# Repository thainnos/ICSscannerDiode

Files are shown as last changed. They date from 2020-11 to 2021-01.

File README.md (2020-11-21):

# A Secure Network Scanner Architecture for Asset Management in Strongly Segmented ICS Networks






<table align="center"><tr><td align="center" width="9999">

</td></tr></table>

This GIT provides all necessary material to setup the network scanner for industrial networks.
The network scanner is based on a strict segmentation between the OT and IT network.
For this two Raspberry Pis, one in the IT network and the other in the OT network are used.
These are communicating over a SPI bus with each other, where a microcontroller is placed in acting
as a data filter/diode.

## Prototype
All this is implemented on a central PCB, where all parts get attached to.
The image below shows the PCB of the network scanner.

<table align="center"><tr><td align="center" width="9999">
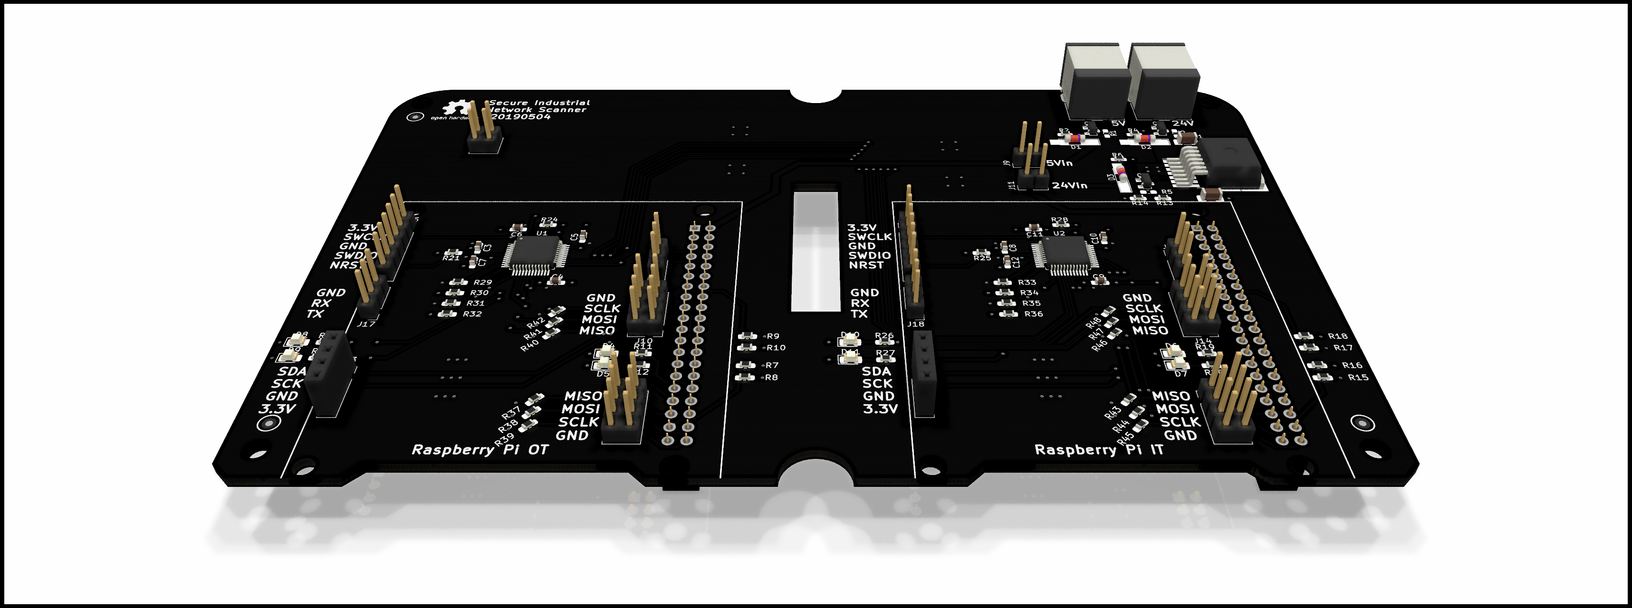
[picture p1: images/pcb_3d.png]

</td></tr></table>

A fully assebled network scanner, with the two Raspberry Pis and OLED displays is illustraed below.

<table align="center"><tr><td align="center" width="9999">

</td></tr></table>

## Scan control and results (Web frontend)

The scan can be started and stopped over the web frontend.
<table align="center"><tr><td align="center" width="9999">
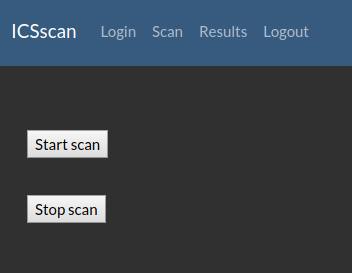
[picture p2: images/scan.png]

</td></tr></table>

The results are shown in a table.
<table align="center"><tr><td align="center" width="9999">
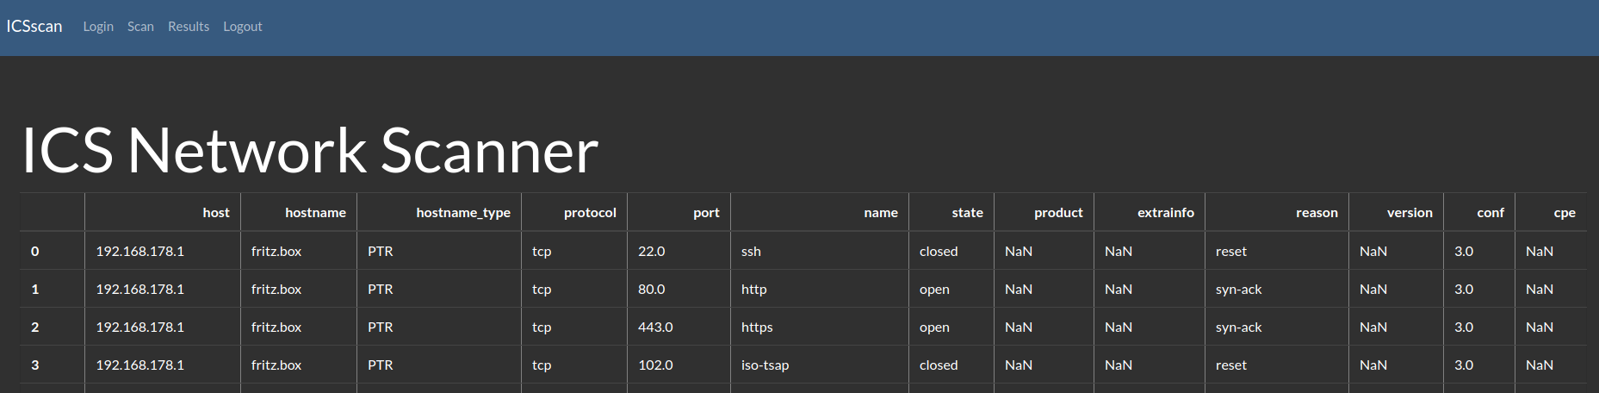
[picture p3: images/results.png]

</td></tr></table>

## Content
* [Software](software/README.md)
* [Hardware](hardware/README.md)
* [Images](images/README.md)

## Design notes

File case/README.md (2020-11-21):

# Case/Mounting Plate for Network Scanner

Modelling with OpenSCAD
'''zsh
sudo add-apt-repository ppa:openscad/releases
sudo apt-get install openscad
'''

Printing with CURA

## 3D Printing

Start the printing and grab a coffee.

<table align="center"><tr><td align="center" width="9999">
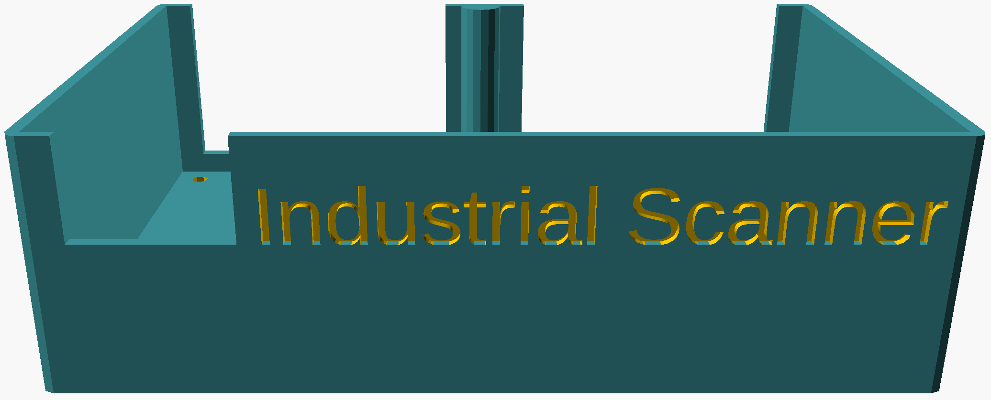
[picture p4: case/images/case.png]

</td></tr></table>

<table align="center"><tr><td align="center" width="9999">
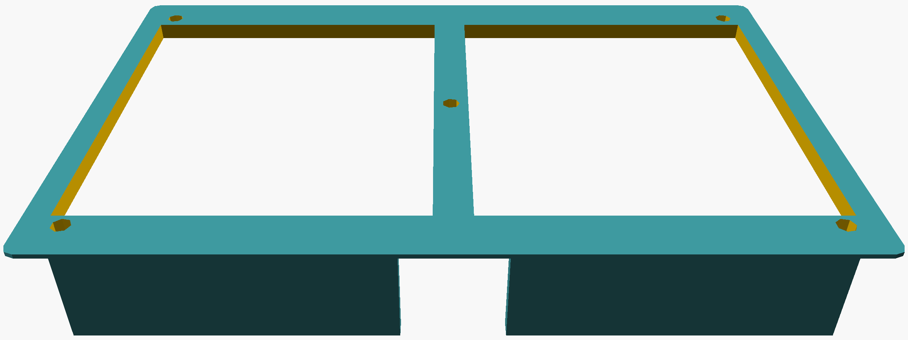
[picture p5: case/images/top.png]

</td></tr></table>

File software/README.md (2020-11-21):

# Software for the Network Scanner

## Components
- [Scanner](scanner/README.md)
- [STM32F030CC](stm32f030cc/README.md)

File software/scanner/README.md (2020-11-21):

# Software Running on each Raspberry Pi for Scanning and Communication Tasks

## Enable I2C, SPI and SSH
```sh
sudo raspi-config
```

## Install dependencies 
Install requirements of python scanner

```sh
python3 -m pip install -r requirements.txt
```

```sh
sudo apt install nmap
```

## Enable booth SPI in bootconfig

```sh
dtparam=spi=on
dtoverlay=spi1-3cs
```

## Enabling autostart

```sh
sudo vim /etc/rc.local
```

```sh
cd /home/pi/gits/networkScanner/software/scanner/
python3 scanner.py
```

## Generating certificates for the Office HTTPs webside

```sh
mkdir certs
cd certs
openssl req -x509 -newkey rsa:4096 -nodes -out cert.pem -keyout key.pem -days 365
```

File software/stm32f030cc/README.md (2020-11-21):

# Software for the STM32 Microcontrollers 

## Toolchain
One possibility is to use the official toolchain provided by ARM ([ARM Toolchain](https://developer.arm.com/tools-and-software/open-source-software/developer-tools/gnu-toolchain/gnu-rm)).
Another possibility is to use the toolchain included by the distribution.

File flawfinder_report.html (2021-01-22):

# Flawfinder Results

Here are the security scan results from Flawfinder version 2.0.15 (https://dwheeler.com/flawfinder), (C) 2001-2019 David A. Wheeler (https://dwheeler.com). Number of rules (primarily dangerous function names) in C/C++ ruleset: 222

Examining ./software/stm32f030cc/Middlewares/Third_Party/FreeRTOS/Source/portable/MemMang/heap_5.c
Examining ./software/stm32f030cc/Middlewares/Third_Party/FreeRTOS/Source/portable/MemMang/heap_4.c
Examining ./software/stm32f030cc/Middlewares/Third_Party/FreeRTOS/Source/portable/MemMang/heap_2.c
Examining ./software/stm32f030cc/Middlewares/Third_Party/FreeRTOS/Source/portable/MemMang/heap_3.c
Examining ./software/stm32f030cc/Middlewares/Third_Party/FreeRTOS/Source/portable/MemMang/heap_1.c
Examining ./software/stm32f030cc/Middlewares/Third_Party/FreeRTOS/Source/portable/GCC/ARM_CM0/port.c
Examining ./software/stm32f030cc/Middlewares/Third_Party/FreeRTOS/Source/portable/GCC/ARM_CM0/portmacro.h
Examining ./software/stm32f030cc/Middlewares/Third_Party/FreeRTOS/Source/stream_buffer.c
Examining ./software/stm32f030cc/Middlewares/Third_Party/FreeRTOS/Source/timers.c
Examining ./software/stm32f030cc/Middlewares/Third_Party/FreeRTOS/Source/tasks.c
Examining ./software/stm32f030cc/Middlewares/Third_Party/FreeRTOS/Source/queue.c
Examining ./software/stm32f030cc/Middlewares/Third_Party/FreeRTOS/Source/include/mpu_wrappers.h
Examining ./software/stm32f030cc/Middlewares/Third_Party/FreeRTOS/Source/include/stack_macros.h
Examining ./software/stm32f030cc/Middlewares/Third_Party/FreeRTOS/Source/include/croutine.h
Examining ./software/stm32f030cc/Middlewares/Third_Party/FreeRTOS/Source/include/queue.h
Examining ./software/stm32f030cc/Middlewares/Third_Party/FreeRTOS/Source/include/deprecated_definitions.h
Examining ./software/stm32f030cc/Middlewares/Third_Party/FreeRTOS/Source/include/task.h
Examining ./software/stm32f030cc/Middlewares/Third_Party/FreeRTOS/Source/include/portable.h
Examining ./software/stm32f030cc/Middlewares/Third_Party/FreeRTOS/Source/include/timers.h
Examining ./software/stm32f030cc/Middlewares/Third_Party/FreeRTOS/Source/include/semphr.h
Examining ./software/stm32f030cc/Middlewares/Third_Party/FreeRTOS/Source/include/StackMacros.h
Examining ./software/stm32f030cc/Middlewares/Third_Party/FreeRTOS/Source/include/FreeRTOSConfig_template.h
Examining ./software/stm32f030cc/Middlewares/Third_Party/FreeRTOS/Source/include/mpu_prototypes.h
Examining ./software/stm32f030cc/Middlewares/Third_Party/FreeRTOS/Source/include/message_buffer.h
Examining ./software/stm32f030cc/Middlewares/Third_Party/FreeRTOS/Source/include/list.h
Examining ./software/stm32f030cc/Middlewares/Third_Party/FreeRTOS/Source/include/projdefs.h
Examining ./software/stm32f030cc/Middlewares/Third_Party/FreeRTOS/Source/include/stream_buffer.h
Examining ./software/stm32f030cc/Middlewares/Third_Party/FreeRTOS/Source/include/event_groups.h
Examining ./software/stm32f030cc/Middlewares/Third_Party/FreeRTOS/Source/include/FreeRTOS.h
Examining ./software/stm32f030cc/Middlewares/Third_Party/FreeRTOS/Source/event_groups.c
Examining ./software/stm32f030cc/Middlewares/Third_Party/FreeRTOS/Source/croutine.c
Examining ./software/stm32f030cc/Middlewares/Third_Party/FreeRTOS/Source/list.c
Examining ./software/stm32f030cc/Middlewares/Third_Party/FreeRTOS/Source/CMSIS_RTOS/cmsis_os.c
Error: encoding error in ./software/stm32f030cc/Middlewares/Third_Party/FreeRTOS/Source/CMSIS_RTOS/cmsis_os.c 'utf-8' codec can't decode byte 0xa9 in position 1078: invalid start byte Python3 requires input character data to be perfectly encoded; it also requires perfectly correct system encoding settings. Unfortunately, your data and/or system settings are not. Here are some options: 1. Run: PYTHONUTF8=0 python3 flawfinder if your system and and data are all properly set up for a non-UTF-8 encoding. 2. Run: PYTHONUTF8=0 LC_ALL=C.ISO-2022 python3 flawfinder if your data has a specific encoding such as ISO-2022 (replace "ISO-2022" with the name of your encoding, and optionally replace "C" with your native language). 3. Run: PYTHONUTF8=0 LC_ALL=C.ISO-8859-1 python3 flawfinder if your data has an unknown or inconsistent encoding (ISO-8859-1 encoders normally allow anything). 4. Convert all your source code to the UTF-8 encoding. The system program "iconv" or Python program "cvt2utf" can do this (for cvt2tuf, you can use "pip install cvt2utf"). 5. Run: python2 flawfinder (That is, use Python 2 instead of Python 3). Some of these options may not work depending on circumstance. In the long term, we recommend using UTF-8 for source code. For more information, see the documentation.

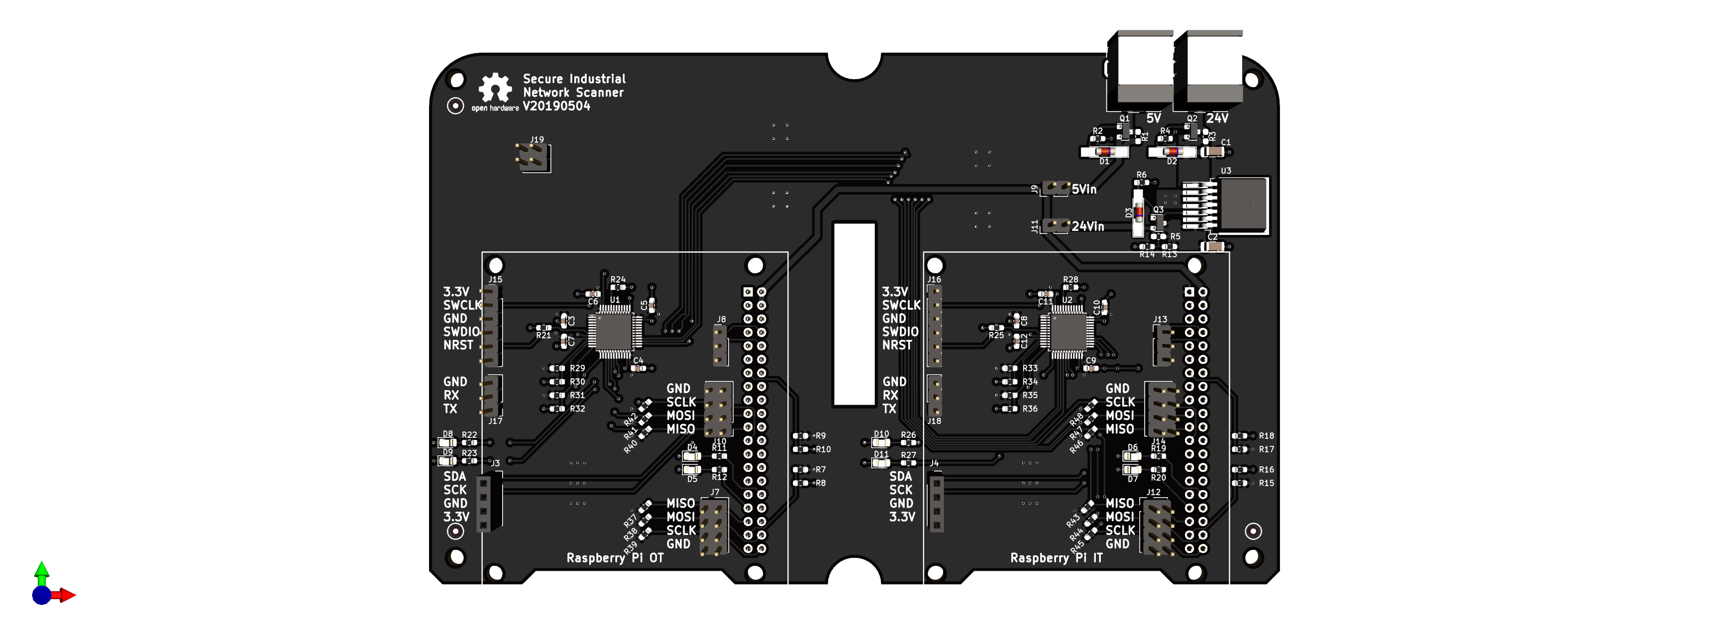
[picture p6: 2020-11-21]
images/pcb_top.png

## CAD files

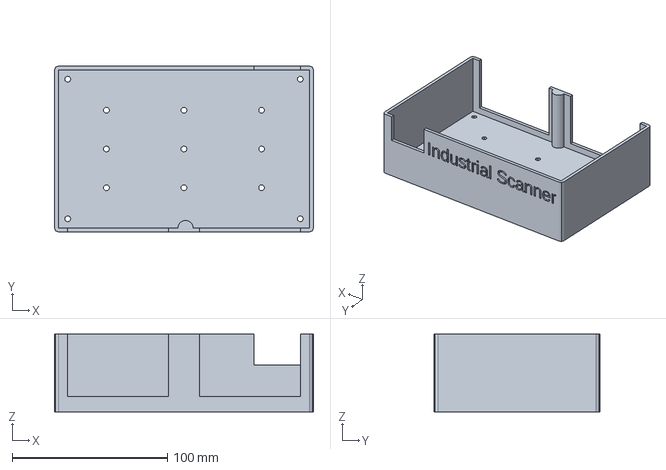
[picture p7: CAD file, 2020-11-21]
case/production_data/Case/case.3mf
167.0 x 107.0 x 50.0 mm

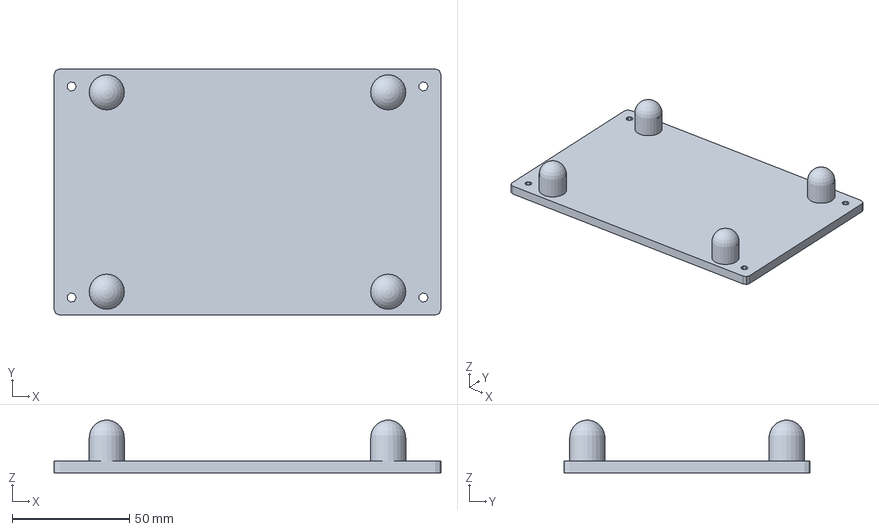
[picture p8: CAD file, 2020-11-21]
case/production_data/Plate/mounting_plate.3mf
165.0 x 105.0 x 22.4 mm

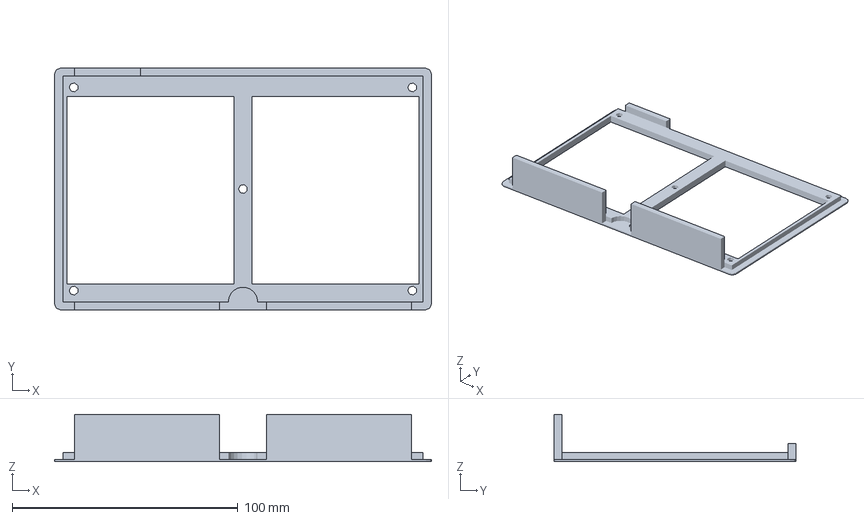
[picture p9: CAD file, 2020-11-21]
case/production_data/top/top.3mf
167.0 x 107.0 x 21.0 mm

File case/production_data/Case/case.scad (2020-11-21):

content = "Industrial Scanner";
font = "Liberation Sans";

union() difference() { 
    translate([-1,-1,0])
    cube(size = [162,102,5], center = false);
    // PCB mount
    translate([5,5,0])
    cylinder( d = 4.00, h = 20);
    translate([155,5,0])
    cylinder( d = 4.00, h = 20);
    translate([5,95,0])
    cylinder( d = 4.00, h = 20);
    translate([155,95,0])
    cylinder( d = 4.00, h = 20);
    
    // Case mount
    translate([30,25,0])
        cylinder( d = 4.00, h = 20);
    translate([80,25,0])
        cylinder( d = 4.00, h = 20);
    translate([130,25,0])
        cylinder( d = 4.00, h = 20);
    translate([30,50,0])
        cylinder( d = 4.00, h = 20);
    translate([80,50,0])
        cylinder( d = 4.00, h = 20);
    translate([130,50,0])
        cylinder( d = 4.00, h = 20);
    translate([30,75,0])
        cylinder( d = 4.00, h = 20);
    translate([80,75,0])
        cylinder( d = 4.00, h = 20);
    translate([130,75,0])
        cylinder( d = 4.00, h = 20);
       
} 



// Rounded corners
union() difference() { // front left
    translate([-1,-1,0])
        cylinder( d = 5.00, h = 50);
    translate([-1,-1,0])
        cube(size = [5,5,50], center = false);
} 
union() difference() { // front right
    translate([161,-1,0])
        cylinder( d = 5.00, h = 50);
    translate([156,-1,0])
        cube(size = [5,5,50], center = false);
} 
union() difference() { // back right
    translate([161,101,0])
        cylinder( d = 5.00, h = 50);
    translate([156,96,0])
        cube(size = [5,5,50], center = false);
} 
union() difference() { // back left
     translate([-1,101,0])
        cylinder( d = 5.00, h = 50);
    translate([-1,96,0])
        cube(size = [5,5,50], center = false);
} 

// Left
translate([-3.5,-1,0])
    cube(size = [2.5,102,50], center = false);
// Right
translate([161,-1,0])
    cube(size = [2.5,102,50], center = false);
// Front
translate([-1,-3.5,0])
    cube(size = [162,2.5,10], center = false);
translate([-1,-3.5,0])
    cube(size = [6,2.5,50], center = false);
translate([155,-3.5,0])
    cube(size = [6,2.5,50], center = false);
translate([70,-3.5,0])
    cube(size = [20,2.5,50], center = false);
union() difference() { // back left
    translate([81,-1,0])
        cylinder(d = 10.00, h = 50);
    translate([70,-13.5,0])
        cube(size = [20,10,50], center = false);
}
// Back
translate([-1,101,0])
    cube(size = [162,2.5,30], center = false);

translate([155,101,0])
        cube(size = [6,2.5,50], center = false);
union() difference() { 
    translate([-1,101,0])
        cube(size = [126,2.5,50], center = false);
    translate ([122,102,30]) {
        rotate([90,0,180])
        linear_extrude(height = 20) {
           text(content, font = font, size = 11);
       }
    }
}

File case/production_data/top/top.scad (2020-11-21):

difference() {
    union() {
        // Base plate
        translate([-1,-1,0])
            cube(size = [162,102,1], center = false);
        // Place in
        translate([0.2,0,-3])
            cube(size = [159.6,100,3], center = false);
    }
    // PCB mount
    translate([5,5,-4])
        cylinder( d = 4.00, h = 40);
    translate([155,5,-4])
        cylinder( d = 4.00, h = 40);
    translate([5,95,-4])
        cylinder( d = 4.00, h = 40);
    translate([155,95,-4])
        cylinder( d = 4.00, h = 40);
    // For case
    translate([80,50,-4])
        cylinder( d = 4.00, h = 20);
    
    //display
    translate([2,8,-3])
        cube(size = [74,83,4], center = false);
    translate([84,8,-3])
        cube(size = [74,83,4], center = false);
    translate([80,0,-3])
        cylinder( d = 13.00, h = 3);
    // many holes
    //for (i = [1 : 15]){
    //    for (j = [1 : 9]){
    //        translate([10*i,10*j,-2])
    //            cylinder( d = 8.00, h = 3);
    //    }
    //}
    

}
//close back
    translate([125.4,100,-7])
        cube(size = [29.2,3.5,7], center = false);
//close left rp
    translate([5.4,-3.5,-20])
        cube(size = [64.2,3.5,20], center = false);
//close right rp
    translate([90.4,-3.5,-20])
        cube(size = [64.2,3.5,20], center = false);

// Rounded corners
// front left
    translate([-1,-1,0])
        cylinder( d = 5.00, h = 1);

// front right
    translate([161,-1,0])
        cylinder( d = 5.00, h = 1);

// back right
    translate([161,101,0])
        cylinder( d = 5.00, h = 1);

// back left
     translate([-1,101,0])
        cylinder( d = 5.00, h = 1);


// Left
translate([-3.5,-1,0])
    cube(size = [2.5,102,1], center = false);
// Right
translate([161,-1,0])
    cube(size = [2.5,102,1], center = false);
// Front
translate([-1,-3.5,0])
    cube(size = [162,2.5,1], center = false);
// Back
translate([-1,101,0])
    cube(size = [162,2.5,1], center = false);

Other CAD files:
case/production_data/Plate/mounting_plate.scad
case/production_data/Case/case.stl
case/production_data/Plate/mounting_plate.stl
case/production_data/top/top.stl

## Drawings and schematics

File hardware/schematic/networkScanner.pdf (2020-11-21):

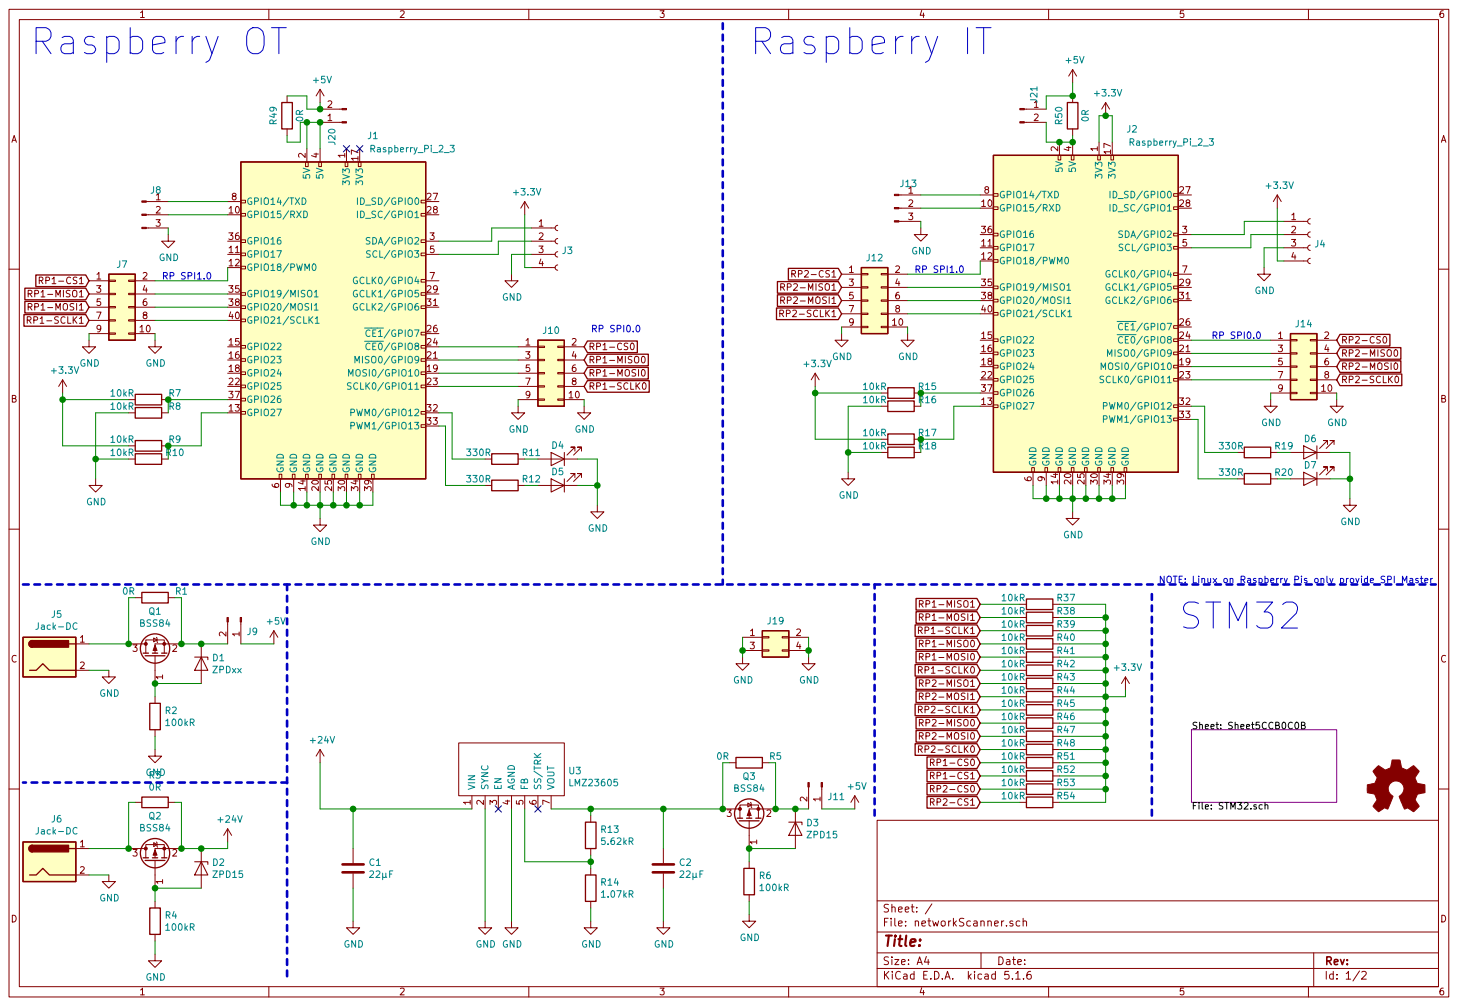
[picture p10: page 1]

9 | 10

NOTE: Linux on Raspberry Pis only provide SPI Master
STM32

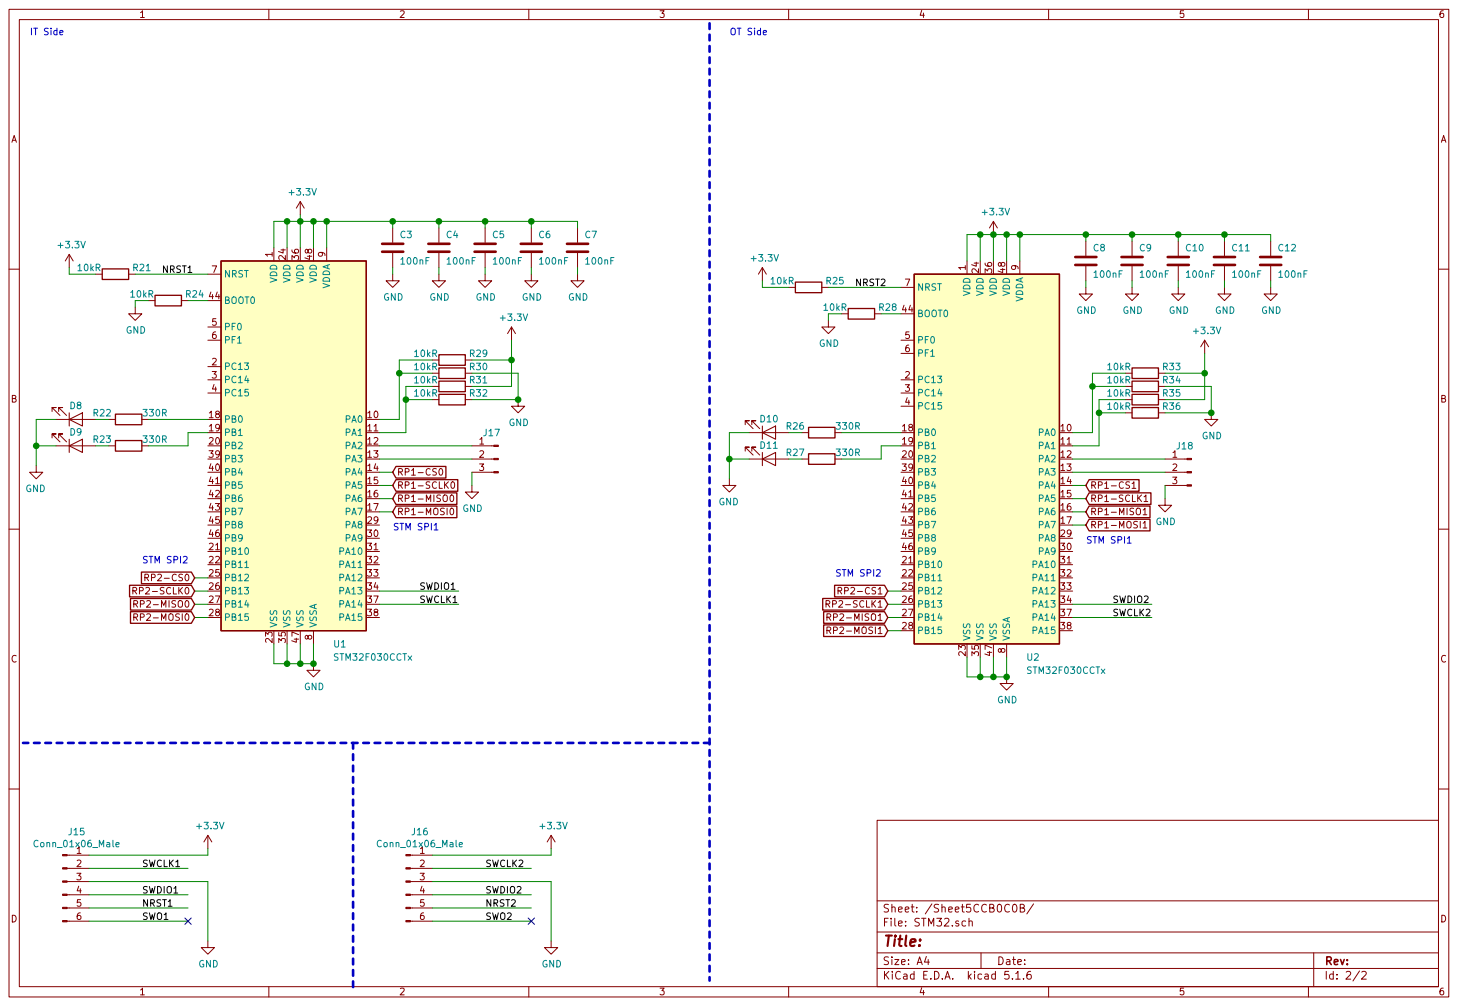
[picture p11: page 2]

1 PA0 10 PA1 11 PA2 12 PA3 13 PA4 14 PA5 15 PA6 16 PA7 17 PB0 18 PB1 19 PC13 2 PB2 20 PB10 21 PB11 22 VSS 23 VDD 24 PB12 25 PB13 26 PB14 27 PB15 28 PA8 29 PC14 3 PA9 30 PA10 31 PA11 32 PA12 33 PA13 34 VSS 35 VDD 36 PA14 37 PA15 38 PB3 39 PC15 4 PB4 40 PB5 41 PB6 42 PB7 43 BOOT0 44 PB8 45 PB9 46 VSS 47 VDD 48 PF0 5 PF1 6 NRST 7 VSSA

Id: 2/2 Title: File: STM32.sch Sheet: /Sheet5CCB0C0B/

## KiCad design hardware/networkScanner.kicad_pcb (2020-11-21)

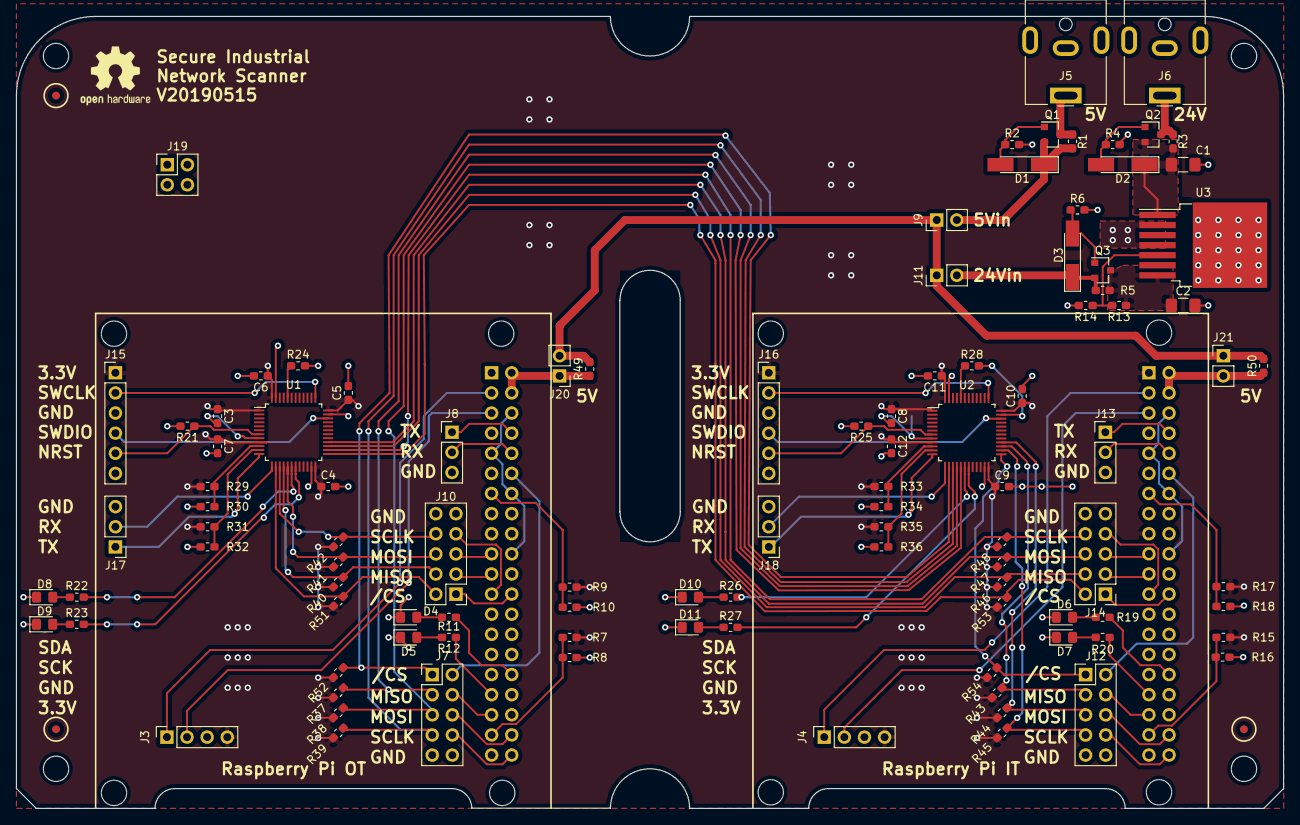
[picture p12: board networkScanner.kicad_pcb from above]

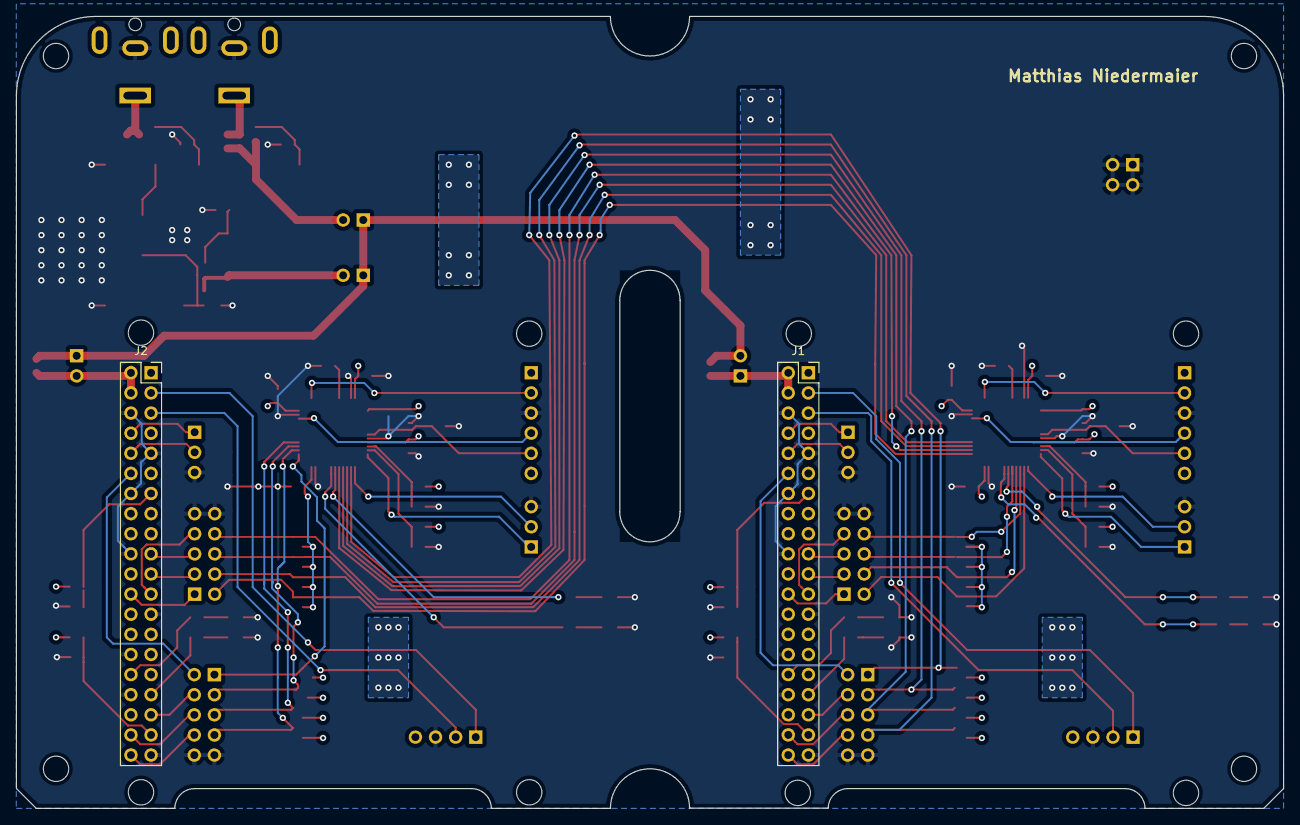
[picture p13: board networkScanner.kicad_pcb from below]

Board: 2 copper layers, 160.0 x 100.0 mm, 104 parts (2 on the bottom side), 91 nets.

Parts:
C1, C2: 22µF; C_1206_3216Metric_Pad1.42x1.75mm_HandSolder
C3, C4, C5, C6, C7, C8, C9, C10, C11, C12: 100nF; C_0603_1608Metric_Pad1.05x0.95mm_HandSolder
D1: ZPDxx; D_MiniMELF_Handsoldering
D2, D3: ZPD15; D_MiniMELF_Handsoldering
D4, D5, D6, D7, D8, D9, D10, D11: LED; LED_0805_2012Metric_Pad1.15x1.40mm_HandSolder
J1, J2: Raspberry_Pi_2_3; PinSocket_2x20_P2.54mm_Vertical
J3, J4: Conn_01x04_Female; PinSocket_1x04_P2.54mm_Vertical
J5, J6: Jack-DC; BarrelJack_CUI_PJ-063AH_Horizontal
J7, J10, J12, J14: Conn_02x05_Odd_Even; PinHeader_2x05_P2.54mm_Vertical
J8, J13, J17, J18: Conn_01x03_Male; PinHeader_1x03_P2.54mm_Vertical
J9, J11, J20, J21: Conn_01x02_Male; PinHeader_1x02_P2.54mm_Vertical
J15, J16: Conn_01x06_Male; PinHeader_1x06_P2.54mm_Vertical
J19: Conn_02x02_Odd_Even; PinHeader_2x02_P2.54mm_Vertical
Q1, Q2, Q3: BSS84; SOT-23
R1, R3, R5, R49, R50: 0R; R_0603_1608Metric_Pad1.05x0.95mm_HandSolder
R2, R4, R6: 100kR; R_0603_1608Metric_Pad1.05x0.95mm_HandSolder
R7, R8, R9, R10, R15, R16, R17, R18, R21, R24, R25, R28, R29, R30, R31, R32, R33, R34, R35, R36, R37, R38, R39, R40, R41, R42, R43, R44, R45, R46, R47, R48, R51, R52, R53, R54: 10kR; R_0603_1608Metric_Pad1.05x0.95mm_HandSolder
R11, R12, R19, R20, R22, R23, R26, R27: 330R; R_0603_1608Metric_Pad1.05x0.95mm_HandSolder
R13: 5.62kR; R_0603_1608Metric_Pad1.05x0.95mm_HandSolder
R14: 1.07kR; R_0603_1608Metric_Pad1.05x0.95mm_HandSolder
U1, U2: STM32F030CCTx; LQFP-48_7x7mm_P0.5mm
U3: LMZ23605; TO-263-7_TabPin4

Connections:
+3V3: C3.1, C4.1, C5.1, C6.1, C7.1, C8.1, C9.1, C10.1, C11.1, C12.1, J2.1, J2.17, J3.4, J4.4, J15.1, J16.1, R7.2, R9.2, R15.2, R17.2, R29.1, R31.1, R33.1, R35.1, R37.1, R38.1, R39.1, R40.1, R41.1, R42.1, R43.1, R44.1, R45.1, R46.1, R47.1, R48.1, R51.1, R52.1, R53.1, R54.1, U1.1, U1.9, U1.24, U1.36, U1.48, U2.1, U2.9, U2.24, U2.36, U2.48
+5V: J9.1, J11.1, J20.2, J21.1, R49.2, R50.2
+24V: C1.1, D2.1, Q2.2, R3.1, U3.1
/Sheet5CCB0C0B/NRST1: J15.5, R21.1, U1.7
/Sheet5CCB0C0B/NRST2: J16.5, R25.1, U2.7
/Sheet5CCB0C0B/SWCLK1: J15.2, U1.37
/Sheet5CCB0C0B/SWCLK2: J16.2, U2.37
/Sheet5CCB0C0B/SWDIO1: J15.4, U1.34
/Sheet5CCB0C0B/SWDIO2: J16.4, U2.34
GND: C1.2, C2.2, C3.2, C4.2, C5.2, C6.2, C7.2, C8.2, C9.2, C10.2, C11.2, C12.2, D4.1, D5.1, D6.1, D7.1, D8.1, D9.1, D10.1, D11.1, J1.6, J1.9, J1.14, J1.20, J1.25, J1.30, J1.34, J1.39, J2.6, J2.9, J2.14, J2.20, J2.25, J2.30, J2.34, J2.39, J3.3, J4.3, J5.2, J6.2, J7.9, J7.10, J8.3, J10.9, J10.10, J12.9, J12.10, J13.3, J14.9, J14.10, J15.3, J16.3, J17.3, J18.3, J19.1, J19.2, J19.3, J19.4, R2.2, R4.2, R6.2, R8.2, R10.2, R14.2, R16.2, R18.2, R21.2, R24.2, R25.2, R28.2, R30.1, R32.1, R34.1, R36.1, U1.8, U1.23, U1.35, U1.47, U2.8, U2.23, U2.35, U2.47, U3.2, U3.4
unnamed: C2.1, Q3.3, R5.2, R13.1, U3.7
unnamed: D1.1, J9.2, Q1.2, R1.1
unnamed: D1.2, Q1.1, R2.1
unnamed: D2.2, Q2.1, R4.1
unnamed: D3.1, J11.2, Q3.2, R5.1
unnamed: D3.2, Q3.1, R6.1
unnamed: D4.2, R11.1
unnamed: D5.2, R12.1
unnamed: D6.2, R19.1
unnamed: D7.2, R20.1
unnamed: D8.2, R22.1
unnamed: D9.2, R23.1
unnamed: D10.2, R26.1
unnamed: D11.2, R27.1
unnamed: J1.2, J1.4, J20.1, R49.1
unnamed: J1.3, J3.1
unnamed: J1.5, J3.2
unnamed: J1.8, J8.1
unnamed: J1.10, J8.2
unnamed: J1.12, J7.2
unnamed: J1.13, R9.1, R10.1
unnamed: J1.19, J10.5
unnamed: J1.21, J10.3
unnamed: J1.23, J10.7
unnamed: J1.24, J10.1
unnamed: J1.32, R11.2
unnamed: J1.33, R12.2
unnamed: J1.35, J7.4
unnamed: J1.37, R7.1, R8.1
unnamed: J1.38, J7.6
unnamed: J1.40, J7.8
unnamed: J2.2, J2.4, J21.2, R50.1
unnamed: J2.3, J4.1
unnamed: J2.5, J4.2
unnamed: J2.13, R17.1, R18.1
unnamed: J2.32, R19.2
unnamed: J2.33, R20.2
unnamed: J2.37, R15.1, R16.1
unnamed: J5.1, Q1.3, R1.2
unnamed: J6.1, Q2.3, R3.2
unnamed: J2.12, J12.2
unnamed: J2.35, J12.4
unnamed: J2.38, J12.6
unnamed: J2.40, J12.8
unnamed: J2.8, J13.1
unnamed: J2.10, J13.2
unnamed: J2.24, J14.1
unnamed: J2.21, J14.3
unnamed: J2.19, J14.5
unnamed: J2.23, J14.7
unnamed: J17.1, U1.12
unnamed: J17.2, U1.13
unnamed: J18.1, U2.12
unnamed: J18.2, U2.13
unnamed: R13.2, R14.1, U3.5
unnamed: R22.2, U1.18
unnamed: R23.2, U1.19
unnamed: R24.1, U1.44
unnamed: R26.2, U2.18
unnamed: R27.2, U2.19
unnamed: R28.1, U2.44
unnamed: R29.2, R30.2, U1.10
unnamed: R31.2, R32.2, U1.11
unnamed: R33.2, R34.2, U2.10
unnamed: R35.2, R36.2, U2.11
RP1-CS0: J10.2, R51.2, U1.14
RP1-CS1: J7.1, R52.2, U2.14
RP1-MISO0: J10.4, R40.2, U1.16
RP1-MISO1: J7.3, R37.2, U2.16
RP1-MOSI0: J10.6, R41.2, U1.17
RP1-MOSI1: J7.5, R38.2, U2.17
RP1-SCLK0: J10.8, R42.2, U1.15
RP1-SCLK1: J7.7, R39.2, U2.15
RP2-CS0: J14.2, R53.2, U1.25
RP2-CS1: J12.1, R54.2, U2.25
RP2-MISO0: J14.4, R46.2, U1.27
RP2-MISO1: J12.3, R43.2, U2.27
RP2-MOSI0: J14.6, R47.2, U1.28
RP2-MOSI1: J12.5, R44.2, U2.28
RP2-SCLK0: J14.8, R48.2, U1.26
RP2-SCLK1: J12.7, R45.2, U2.26

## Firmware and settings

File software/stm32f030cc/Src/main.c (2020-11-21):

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

/* Includes ------------------------------------------------------------------*/
#include "main.h"
#include "cmsis_os.h"

/* USER CODE BEGIN Includes */
#include "stdio.h"
#include "string.h"
#include "stdlib.h"
#include  <errno.h>
#include  <sys/unistd.h> // STDOUT_FILENO, STDERR_FILENO
#include "colors.h"
/* USER CODE END Includes */

/* USER CODE BEGIN PD */
#define MESSAGE_SIZE 2048

/* USER CODE END PD */

SPI_HandleTypeDef hspi1;
SPI_HandleTypeDef hspi2;
DMA_HandleTypeDef hdma_spi1_tx;
DMA_HandleTypeDef hdma_spi1_rx;
DMA_HandleTypeDef hdma_spi2_tx;
DMA_HandleTypeDef hdma_spi2_rx;

UART_HandleTypeDef huart2;

osThreadId defaultTaskHandle;
osThreadId ledTaskHandle;
osThreadId spiRecTaskHandle;
osThreadId spiTraTaskHandle;
/* USER CODE BEGIN PV */
uint16_t deviceID=0;
uint8_t data[MESSAGE_SIZE];
uint8_t senddata[MESSAGE_SIZE];
uint8_t sendcomplete;
uint8_t receivecomplete;
/* USER CODE END PV */

void SystemClock_Config(void);
static void MX_GPIO_Init(void);
static void MX_DMA_Init(void);
static void MX_SPI1_Init(void);
static void MX_SPI2_Init(void);
static void MX_USART2_UART_Init(void);
void StartDefaultTask(void const * argument);
void ledFunc(void const * argument);
void spiRecFunc(void const * argument);
void spiTraFunc(void const * argument);

/* USER CODE BEGIN 0 */
int _write(int file, char *data, int len){
    if ((file != STDOUT_FILENO) && (file != STDERR_FILENO)){
        errno = EBADF;
        return -1;
    }

    // arbitrary timeout 1
    HAL_StatusTypeDef status = HAL_OK;
    status = HAL_UART_Transmit(&huart2, (uint8_t*)data, len, 100);

    // return # of bytes written - as best we can tell
    return (status == HAL_OK ? len : 0);
}
/* USER CODE END 0 */

/**
  * @brief  The application entry point.
  * @retval int
  */
int main(void)
{
  /* MCU Configuration--------------------------------------------------------*/

  /* Reset of all peripherals, Initializes the Flash interface and the Systick. */
  HAL_Init();

  /* Configure the system clock */
  SystemClock_Config();

  /* Initialize all configured peripherals */
  MX_GPIO_Init();
  MX_DMA_Init();
  MX_SPI1_Init();
  MX_SPI2_Init();
  MX_USART2_UART_Init();
  /* USER CODE BEGIN 2 */
  printf("\n\n\r+++++++++++++++++++++++++++++++++++++++\n");
  printf("\rBuild: %s - %s\n", __DATE__, __TIME__);
  printf("\r%sInit done!\n", CRST);

  if(HAL_GPIO_ReadPin(GPIOA, GPIO_PIN_0)){
    printf("\rGPIO_PIN_A05 is high\n");
    deviceID += 2;
  }
  if(HAL_GPIO_ReadPin(GPIOA, GPIO_PIN_1)){
    printf("\rGPIO_PIN_A06 is high\n");
    deviceID += 1;
  }
  if((deviceID == 0) || (deviceID == 3)){
    while(1){
      printf("\rError: No resistors for device codeing?!\n");
      HAL_Delay(100);  
    }
  }


  printf("\rDeviceID: %u\n", (unsigned int)deviceID);
  printf("\rDeviceSE: %u\n", (unsigned int)HAL_GetDEVID);
  /* USER CODE END 2 */

  /* USER CODE BEGIN RTOS_MUTEX */
  /* add mutexes, ... */
  /* USER CODE END RTOS_MUTEX */

  /* USER CODE BEGIN RTOS_SEMAPHORES */
  /* add semaphores, ... */
  /* USER CODE END RTOS_SEMAPHORES */

  /* USER CODE BEGIN RTOS_TIMERS */
  /* start timers, add new ones, ... */
  /* USER CODE END RTOS_TIMERS */

  /* USER CODE BEGIN RTOS_QUEUES */
  /* add queues, ... */
  /* USER CODE END RTOS_QUEUES */

  /* Create the thread(s) */
  /* definition and creation of defaultTask */
  osThreadDef(defaultTask, StartDefaultTask, osPriorityNormal, 0, 128);
  defaultTaskHandle = osThreadCreate(osThread(defaultTask), NULL);

  /* definition and creation of ledTask */
  osThreadDef(ledTask, ledFunc, osPriorityNormal, 0, 128);
  ledTaskHandle = osThreadCreate(osThread(ledTask), NULL);

  /* definition and creation of spiRecTask */
  osThreadDef(spiRecTask, spiRecFunc, osPriorityHigh, 0, 512);
  spiRecTaskHandle = osThreadCreate(osThread(spiRecTask), NULL);

  /* definition and creation of spiTraTask */
  osThreadDef(spiTraTask, spiTraFunc, osPriorityAboveNormal, 0, 512);
  spiTraTaskHandle = osThreadCreate(osThread(spiTraTask), NULL);

  /* USER CODE BEGIN RTOS_THREADS */
  /* add threads, ... */
  /* USER CODE END RTOS_THREADS */

  /* Start scheduler */
  osKernelStart();
 
  /* We should never get here as control is now taken by the scheduler */
  /* Infinite loop */
  /* USER CODE BEGIN WHILE */
  while (1)
  {
    /* USER CODE END WHILE */

    /* USER CODE BEGIN 3 */
  }
  /* USER CODE END 3 */
}

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
/* USER CODE BEGIN Header_StartDefaultTask */
/**
  * @brief  Function implementing the defaultTask thread.
  * @param  argument: Not used 
  * @retval None
  */
/* USER CODE END Header_StartDefaultTask */
void StartDefaultTask(void const * argument)
{
  /* USER CODE BEGIN 5 */
  osDelay(5);
  printf("\rDefault Task started\n");
  /* Infinite loop */
  for(;;)
  {
    osDelay(100);
  }
  /* USER CODE END 5 */ 
}

/* USER CODE BEGIN Header_ledFunc */
/**
* @brief Function implementing the ledTask thread.
* @param argument: Not used
* @retval None
*/
/* USER CODE END Header_ledFunc */
void ledFunc(void const * argument)
{
  /* USER CODE BEGIN ledFunc */
  osDelay(10);
  printf("\rLED Toggle Task started\n");
  /* Infinite loop */
  for(;;)
  {
    HAL_GPIO_TogglePin(led0_GPIO_Port, led0_Pin);
    osDelay(1000);
  }
  /* USER CODE END ledFunc */
}

/* USER CODE BEGIN Header_spiRecFunc */
/**
* @brief Function implementing the spiRecTask thread.
* @param argument: Not used
* @retval None
*/
/* USER CODE END Header_spiRecFunc */
void spiRecFunc(void const * argument)
{
  /* USER CODE BEGIN spiRecFunc */
  receivecomplete = 0;
  memset(data, 0, MESSAGE_SIZE);
  memset(senddata, 0, MESSAGE_SIZE);
  osDelay(100);
  printf("\rSPI Receive Task started\n");
  /* Infinite loop */
  for(;;)
  {
    osDelay(1);
    memset(data, 0, MESSAGE_SIZE);
    receivecomplete = 0;
    if(deviceID == 1){
      HAL_SPI_Receive_DMA(&hspi1, data, MESSAGE_SIZE);
    }
    else if(deviceID == 2){
      HAL_SPI_Receive_DMA(&hspi2, data, MESSAGE_SIZE);
    }
    else{
      printf("\rERROR: Device ID not specified.\n");
      continue;	
    }
    while(receivecomplete == 0){
      // This loop will be executed until data is recieved
      osDelay(10);
    }
    printf("\rReceived: %s\n", data);
    if(data[0] == 't'){
      printf("\rReceived test message, which will be just forwarded.\n");
      HAL_GPIO_TogglePin(led1_GPIO_Port, led1_Pin);
      strncpy((char*)senddata,(char*)data, sizeof(senddata));
    }
    else if(data[0] == 's'){
      printf("\rReceived scan order. Check parameters.\n");
      HAL_GPIO_TogglePin(led1_GPIO_Port, led1_Pin);
      strncpy((char*)senddata,(char*)data, sizeof(senddata));
    }
    else if(data[0] == 'r'){
      printf("\rReceived scan results.\n");
      HAL_GPIO_TogglePin(led1_GPIO_Port, led1_Pin);
      strncpy((char*)senddata,(char*)data, sizeof(senddata));
    }
    else{
      printf("\rNo valid command. Drop message.\n");
    }
  }
  /* USER CODE END spiRecFunc */
}

/* USER CODE BEGIN Header_spiTraFunc */
/**
* @brief Function implementing the spiTraTask thread.
* @param argument: Not used
* @retval None
*/
/* USER CODE END Header_spiTraFunc */
void spiTraFunc(void const * argument)
{
  /* USER CODE BEGIN spiTraFunc */
  osDelay(200);
  sendcomplete=0;
  printf("\rSPI Transmit Task started\n");
  /* Infinite loop */
  for(;;)
  {
    osDelay(10);
    while(senddata[0] == 0){
      // This loop will be executed until data to send is available
      osDelay(10);
    }
    if(deviceID == 1){
      HAL_SPI_Transmit_DMA(&hspi2, senddata, MESSAGE_SIZE);
    }
    else if(deviceID == 2){
      HAL_SPI_Transmit_DMA(&hspi1, senddata, MESSAGE_SIZE);
    }
    else{
      printf("\rERROR: Device ID not specified.\n");
      continue;	
    }
    while(sendcomplete==0){
      // This loop will be executed until data is sent
      osDelay(10);
    }
    osDelay(1000);
    memset(senddata, 0, MESSAGE_SIZE);
  }
  /* USER CODE END spiTraFunc */
}

 /**
  * @brief  Period elapsed callback in non blocking mode
  * @note   This function is called  when TIM1 interrupt took place, inside
  * HAL_TIM_IRQHandler(). It makes a direct call to HAL_IncTick() to increment
  * a global variable "uwTick" used as application time base.
  * @param  htim : TIM handle
  * @retval None
  */
void HAL_TIM_PeriodElapsedCallback(TIM_HandleTypeDef *htim)
{
  if (htim->Instance == TIM1) {
    HAL_IncTick();
  }
}

/**
  * @brief  This function is executed in case of error occurrence.
  * @retval None
  */
void Error_Handler(void)
{
  /* USER CODE BEGIN Error_Handler_Debug */
  /* User can add his own implementation to report the HAL error return state */

  /* USER CODE END Error_Handler_Debug */
}

#ifdef  USE_FULL_ASSERT
/**
  * @brief  Reports the name of the source file and the source line number
  *         where the assert_param error has occurred.
  * @param  file: pointer to the source file name
  * @param  line: assert_param error line source number
  * @retval None
  */
void assert_failed(uint8_t *file, uint32_t line)
{ 
  /* USER CODE BEGIN 6 */
  /* User can add his own implementation to report the file name and line number,
     tex: printf("Wrong parameters value: file %s on line %d\r\n", file, line) */
  /* USER CODE END 6 */
}
#endif /* USE_FULL_ASSERT */

/************************ (C) COPYRIGHT STMicroelectronics *****END OF FILE****/

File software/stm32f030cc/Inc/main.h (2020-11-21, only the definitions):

#define deviceID0_Pin GPIO_PIN_0
#define deviceID0_GPIO_Port GPIOA
#define deviceID1_Pin GPIO_PIN_1
#define deviceID1_GPIO_Port GPIOA
#define led0_Pin GPIO_PIN_0
#define led0_GPIO_Port GPIOB
#define led1_Pin GPIO_PIN_1
#define led1_GPIO_Port GPIOB

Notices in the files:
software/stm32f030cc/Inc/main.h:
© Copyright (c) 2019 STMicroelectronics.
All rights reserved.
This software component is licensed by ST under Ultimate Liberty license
